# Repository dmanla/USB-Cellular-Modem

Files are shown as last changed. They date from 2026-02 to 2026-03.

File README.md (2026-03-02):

# USB-Cellular-Modem: NB-IoT/Cat-M Terminal

## Overview
**USB-Cellular-Modem** is an open-hardware cellular terminal designed for to enable any device equipped with USB to interface with LTE-CAT-M1 or NB-IOT Cellular Networks. The modem is low-power enough to be used as a back-up cellular interface for any mobile device. 

**NOTE:** Due to Apple restrictions on USB Interface access, this device cannot interface with Apple Devices. There may be a bluetooth variant in the future.

The core of the device is the **SIMCOM 7080G**, providing global NB-IoT and Cat-M1 connectivity with a focus on a minimal RF footprint and user-controlled privacy.

---

## Key Security & Design Features
* **Active-Discharge Kill Switch**: A physical SPDT slide switch ($SW1$) that disconnects the buck converter and actively shorts the $+BATT$ rail to ground through a $10\Omega$ resistor ($R4$). This ensures the $1000\mu F$ bulk capacitance is drained in milliseconds, preventing any residual "heartbeat" transmissions.
* **UART Signal Isolation**: $1k\Omega$ series resistors ($R8$, $R9$, $R10$, $R11$) are placed on all data lines (TX, RX, RTS, DTR). This prevents the **CH343P** from "back-powering" the modem via internal ESD diodes when the master power is cut.
* **Automated Power Trigger**: The **DTR** line is tied to a **DTC143Z** digital transistor ($Q1$). Opening the serial port on the host machine automatically pulses the modem's **PWRKEY**, initiating the boot sequence.
* **Local RF Shielding**: The PCB includes grounded rectangular frames designed for soldering a metal Faraday cage over the antenna matching network ($J1$, $C2$, $R1$, $C3$) to mitigate local signal sniffing.
* **eSIM Integration**: Includes a dedicated footprint for the **ST4SIM-200M** GSMA-certified eSIM for tamper-resistant credential storage.

---

### Included Hardware
| Component | Part Number | Description |
| :--- | :--- | :--- |
| **Cellular Module** | **SIMCOM 7080G** | Global NB-IoT / Cat-M1 with GNSS. |
| **USB-UART Bridge** | **WCH CH343P** | High-speed USB to serial converter. |
| **Power Regulator** | **TPS62A01ADRL** | 1000mA Synchronous Buck Converter (5V to 3.8V). |
| **Embedded SIM** | **ST4SIM-200M** | Industrial-grade MFF2 eSIM. |
| **Nano SIM Slot** | **CUI Hinged NSIM-2** | Nano-SIM Card Slot. |

---

## Technical Specifications
* **Input Power**: USB VBUS (+5V, 500mA).
* **Logic Level**: $1.8V$ Internal ($VDD\_EXT$), isolated from $3.3V$ USB signals.
* **Stackup**: 4-Layer PCB with solid internal ground planes.
* **EDA Software**: **KiCad 9.0.7**.

## Usage
1.  **Enable Device**: Flip $SW1$ to the `ON` position.
2.  **Communication**: Open a serial terminal (e.g., `minicom` or `screen`) at `115200` baud. The DTR toggle will boot the modem.
3.  **Kill Session**: Flip $SW1$ to the `OFF` position. The modem is physically disconnected and the power rail is grounded.

---

## Front 3D Render


## Back 3D Render


## License

Dimensions and Modem Placement Derived from [techstudio-design/sim7080_dev_board](https://github.com/techstudio-design/sim7080_dev_board)

All PCB design files and hardware are released under the [Creative Commons Attribution Share Alike 4.0](https://choosealicense.com/licenses/cc-by-sa-4.0/) license.

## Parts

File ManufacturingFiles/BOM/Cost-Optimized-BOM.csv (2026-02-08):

Reference | Qty | Value/Description | Manufacturer | Part Number | Distributor | Unit Price (10 Qty) | Total (10 Qty)
U2 | 1 | Cellular Module Cat-M/NB-IoT | SimCom | SIM7080G | LCSC (C2943992) | $10.86 | $108.60
U3 | 1 | eSIM IC GSMA | STMicroelectronics | ST4SIM-200M | Mouser / ST | $3.00 | $30.00
U7 | 1 | USB to UART Bridge | WCH | CH343P | LCSC (C2846043) | $1.03 | $10.30
U6 | 1 | Buck Converter 1A | Texas Instruments | TPS62A01ADRLR | DigiKey / Mouser | $0.13 | $1.30
U1,U4 | 2 | ESD Protection 2-Line | Yenji Elec | USBLC6-2SC6 | LCSC (C323793) | $0.07 | $1.40
D2 | 1 | TVS Diode Array 5-Line | STMicroelectronics | ESDA6V1W5 | LCSC (C48677) | $0.10 | $1.00
C1,C18 | 2 | 470uF 6.3V Tantalum Case D | Kyocera AVX | TAJD477K006RNJ | LCSC (C7229) | $0.86 | $17.20
J1 | 1 | U.FL Connector (SMT) | Hirose (HRS) | U.FL-R-SMT-1(80) | LCSC (C88374) | $0.13 | $1.30
J3 | 1 | USB Micro-B Connector | Shou Han | Micro-USB-5P | LCSC (C10418) | $0.04 | $0.40
J4 | 1 | Nano SIM Connector Hinged | Shou Han | NANO SIM 7P H1.37 | LCSC (C7529384) | $0.27 | $2.70
SW1 | 1 | Slide Switch SPDT | XKB Connectivity | SS-12D10-G5 | LCSC (C394953) | $0.03 | $0.30
F1 | 1 | PTC Fuse 1.1A 1206 | SART | SMD1206-110-16V | LCSC (C20537) | $0.04 | $0.40
L1 | 1 | Inductor 1uH 1A 1210 | Sunlord | SWPA3015S1R0MT | LCSC (C1046) | $0.05 | $0.50
Q1,Q2,Q3 | 3 | Digital Transistor NPN | Changjiang | DTC143ZUA | LCSC (C151046) | $0.02 | $0.60
D3 | 1 | LED Blue 0603 | Hubei Kento | 19-217/BHC-ZL1M2RY/3T | LCSC (C2293) | $0.02 | $0.20
D4 | 1 | LED Red 0603 | Hubei Kento | 17-21/R6C-AP1Q2L/3T | LCSC (C2290) | $0.02 | $0.20
C4,C5 | 2 | 100uF 6.3V X5R 1206 | Samsung | CL31A107MQHNNNE | LCSC (C14863) | $0.14 | $2.80
C17 | 1 | 22uF 10V X5R 0805 | Samsung | CL21A226MPQNNNE | LCSC (C15652) | $0.03 | $0.30
C16 | 1 | 10uF 10V X5R 0805 | Samsung | CL21A106KPCLQNC | LCSC (C15783) | $0.01 | $0.10
C6,C10,C13 | 3 | 1uF 16V X7R 0603 | Samsung | CL10B105KO8NNNC | LCSC (C15849) | $0.00 | $0.12
C11 | 1 | 100nF 16V X7R 0603 | Samsung | CL10B104KB8NNNC | LCSC (C1525) | $0.00 | $0.03
C7,C8,C9 | 3 | 100nF 16V X7R 0603 | Samsung | CL10B104KB8NNNC | LCSC (C1525) | $0.00 | $0.09
C12 | 1 | 120pF 50V C0G 0603 | Samsung | CL10C121JB8NNNC | LCSC (C1548) | $0.00 | $0.03
R6 | 1 | 100k 1% 0603 | Uni-Royal | 0603WAF1003T5E | LCSC (C25804) | $0.00 | $0.02
R5 | 1 | 536k 1% 0603 | Uni-Royal | 0603WAF5363T5E | LCSC (C23187) | $0.00 | $0.02
R2 | 1 | 10k 1% 0603 | Uni-Royal | 0603WAF1002T5E | LCSC (C25744) | $0.00 | $0.02
R3,R7,R8,R9,R11 | 5 | 1k 1% 0603 | Uni-Royal | 0603WAF1001T5E | LCSC (C25741) | $0.00 | $0.10
R4 | 1 | 10R 1% 1210 | Uni-Royal | 1210WAF100JT5E | LCSC (C17918) | $0.01 | $0.10
R1 | 1 | 0R Jumper 0603 | Uni-Royal | 0603WAF0000T5E | LCSC (C21189) | $0.00 | $0.02
JP1 | 1 | Solder Jumper Open | N/A | N/A | N/A | $0.00 | $0.00
J2 | 1 | Pin Header 1x04 | Generic | 2.54mm-1x4P | LCSC (C124375) | $0.01 | $0.10
H1-H4 | 4 | Mounting Hole M2.5 | N/A | N/A | N/A | $0.00 | $0.00
C2,C3 | 2 | DNP | N/A | N/A | N/A | $0.00 | $0.00
 |  |  |  |  |  | Total Unit Cost (Qty: 10) | $18.03

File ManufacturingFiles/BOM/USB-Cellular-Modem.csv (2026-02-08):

Reference | Qty | Value/Description | Footprint | Manufacturer | Part Number | Unit Price (10 Qty) | Total (10 Qty)
U2 | 1 | Cellular Module Cat-M/NB-IoT | LCC-80 (17.6x15.7mm) | SimCom | SIM7080G | $19.72 | $197.20
U3 | 1 | eSIM IC GSMA | VFDFPN8 (2x3mm) | STMicroelectronics | ST4SIM-200M | $3.00 | $30.00
U7 | 1 | USB to UART Bridge | QFN-16 (3x3mm) | WCH | CH343P | $1.03 | $10.30
U6 | 1 | Buck Converter 1A | SOT-563 | Texas Instruments | TPS62A01ADRLR | $0.13 | $1.30
U1,U4 | 2 | ESD Protection 2-Line | SOT-23-6 | STMicroelectronics | USBLC6-2SC6 | $0.24 | $4.80
D2 | 1 | TVS Diode Array 5-Line | SOT-353 (SC-70-5) | STMicroelectronics | ESDA6V1W5 | $0.24 | $2.40
C1,C18 | 2 | 470uF 6.3V Tantalum Case D | 2917 (7343 Metric) | Vishay / Sprague | TR3D477M6R3C0200 | $1.45 | $29.00
J1 | 1 | U.FL Connector | U.FL (SMT) | Hirose | U.FL-R-SMT-1(10) | $1.10 | $11.00
J3 | 1 | USB Micro-B Connector | USB Micro-B (SMT) | XKB Connectivity | U254-051T-4BH83-F1S | $0.13 | $1.30
J4 | 1 | Nano SIM Connector Hinged | Nano-SIM (SMT) | CUI Devices | NSIM-2-C | $0.55 | $5.50
SW1 | 1 | Slide Switch SPDT | SPDT Right Angle | C&K | OS102011MA1Q | $0.54 | $5.40
F1 | 1 | PTC Fuse 1.1A Hold | 1206 (3216 Metric) | Bel Fuse | 0ZCJ0110FF2E | $0.22 | $2.20
L1 | 1 | Inductor 1uH 1A | 1210 (3225 Metric) | Murata | LQH32CN1R0M33L | $0.08 | $0.80
Q1,Q2,Q3 | 3 | Digital Transistor NPN | SOT-323 (SC-70) | Rohm Semiconductor | DTC143ZUA | $0.23 | $6.90
D3 | 1 | LED Blue (NETLIGHT) | 0603 (1608 Metric) | Lite-On | LTST-C190TBKT | $0.10 | $1.00
D4 | 1 | LED Red (STATUS) | 0603 (1608 Metric) | Lite-On | LTST-C190KRKT | $0.10 | $1.00
C4,C5 | 2 | 100uF 6.3V X5R | 1206 (3216 Metric) | Samsung | CL31A107MQHNNNE | $0.20 | $4.00
C17 | 1 | 22uF 10V X5R | 0805 (2012 Metric) | Samsung | CL21A226MPQNNNE | $0.10 | $1.00
C16 | 1 | 10uF 10V X5R | 0805 (2012 Metric) | Samsung | CL21A106KPCLQNC | $0.05 | $0.50
C6,C10,C13 | 3 | 1uF 16V X7R | 0603 (1608 Metric) | Yageo | CC0603KRX7R7BB105 | $0.02 | $0.60
C11 | 1 | 100nF 16V X7R | 0603 (1608 Metric) | Yageo | CC0603KRX7R7BB104 | $0.01 | $0.10
C7,C8, | 2 | DNP | 0603 (1608 Metric) | N/A | N/A | $0.00 | $0.00
 |  |  |  |  |  | Unit Cost (Qty: 10) | $31.63

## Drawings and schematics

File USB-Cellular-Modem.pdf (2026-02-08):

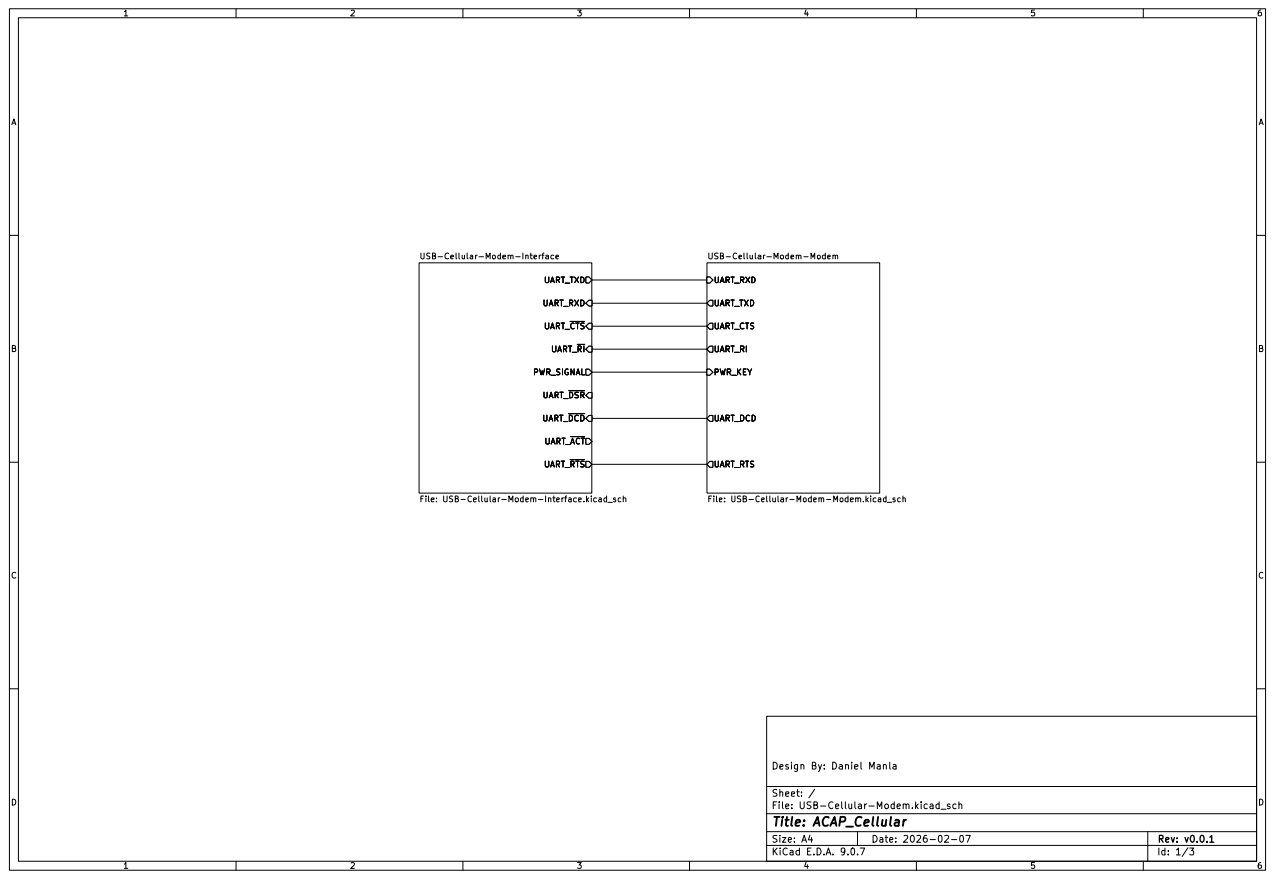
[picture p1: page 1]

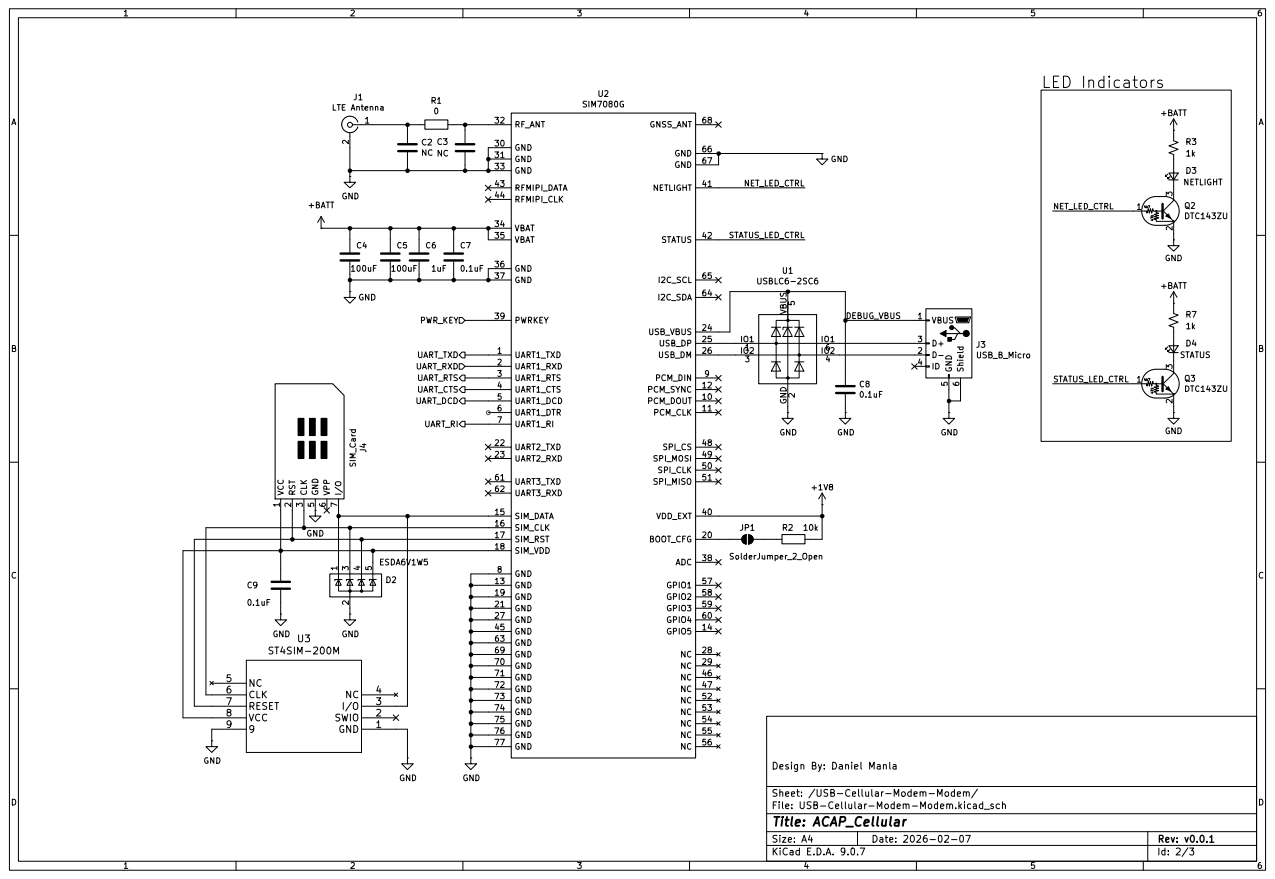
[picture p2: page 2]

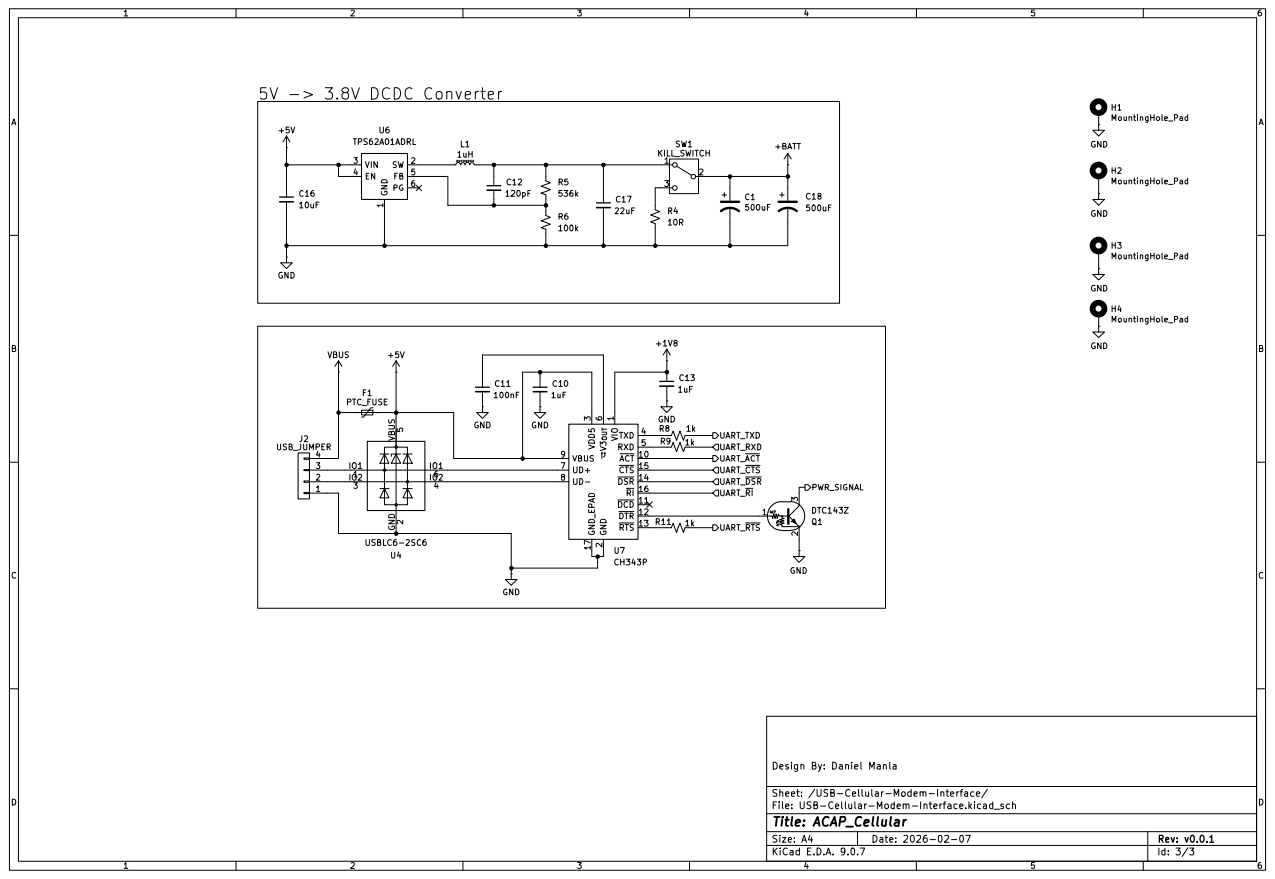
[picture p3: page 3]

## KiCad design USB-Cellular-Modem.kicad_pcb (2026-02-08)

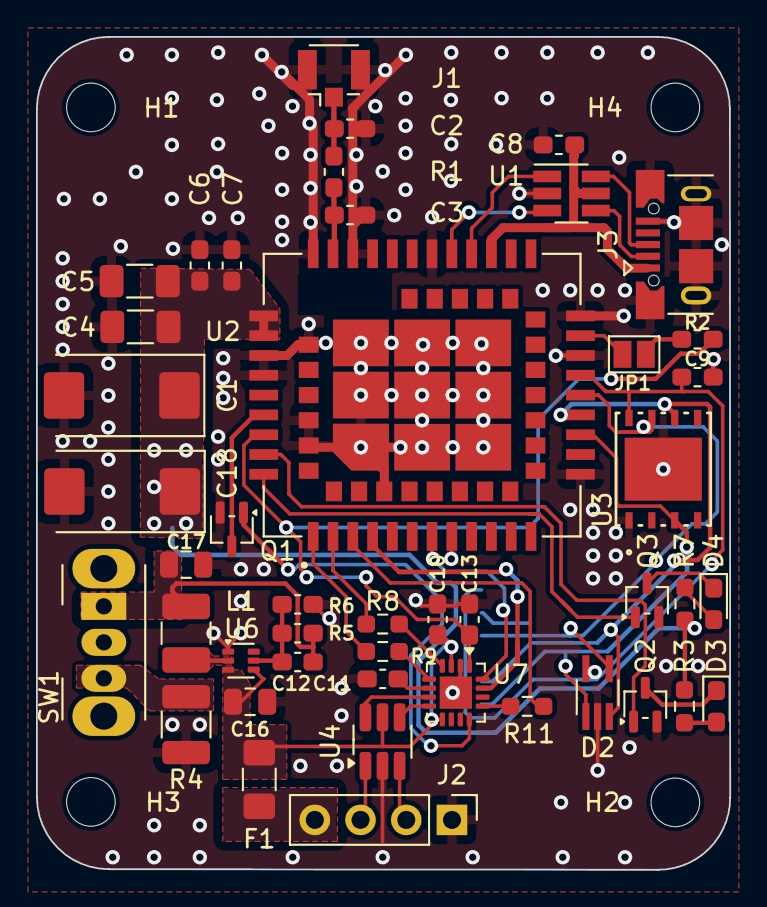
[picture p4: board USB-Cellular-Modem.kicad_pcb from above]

Board: 4 copper layers, 38.5 x 46.3 mm, 50 parts (1 on the bottom side), 43 nets.

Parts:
C1, C18: 500uF; CP_EIA-7343-30_AVX-N_HandSolder
C2, C3: NC; C_0603_1608Metric_Pad1.05x0.95mm_HandSolder
C4, C5: 100uF; C_1206_3216Metric_Pad1.33x1.80mm_HandSolder
C6: 1uF; C_0603_1608Metric_Pad1.05x0.95mm_HandSolder
C7, C8, C9: 0.1uF; C_0603_1608Metric_Pad1.05x0.95mm_HandSolder
C10, C13: 1uF; C_0603_1608Metric_Pad1.08x0.95mm_HandSolder
C11: 100nF; C_0603_1608Metric_Pad1.08x0.95mm_HandSolder
C12: 120pF; C_0603_1608Metric_Pad1.08x0.95mm_HandSolder
C16: 10uF; C_0805_2012Metric
C17: 22uF; C_0805_2012Metric
D2: ESDA6V1W5; SOT-353_SC-70-5_Handsoldering
D3: NETLIGHT; LED_0603_1608Metric_Pad1.05x0.95mm_HandSolder
D4: STATUS; LED_0603_1608Metric_Pad1.05x0.95mm_HandSolder
F1: PTC_FUSE; Fuse_1206_3216Metric_Pad1.42x1.75mm_HandSolder
H1, H2, H3, H4: MountingHole_Pad; MountingHole_2.7mm_M2.5
J1: LTE Antenna; U.FL_Hirose_U.FL-R-SMT-1_Vertical
J2: USB_JUMPER; PinHeader_1x04_P2.54mm_Vertical
J3: USB_B_Micro; USB_Micro-B_XKB_U254-051T-4BH83-F1S
J4: SIM_Card; nanoSIM_Hinged_CUI_NSIM-2-C
JP1: SolderJumper_2_Open; SolderJumper-2_P1.3mm_Open_Pad1.0x1.5mm
L1: 1uH; L_1210_3225Metric_Pad1.42x2.65mm_HandSolder
Q1: DTC143Z; SOT-323_SC-70
Q2, Q3: DTC143ZU; SOT-323_SC-70
R1: 0; R_0603_1608Metric_Pad1.05x0.95mm_HandSolder
R2: 10k; R_0603_1608Metric_Pad1.05x0.95mm_HandSolder
R3, R7, R8, R9, R11: 1k; R_0603_1608Metric_Pad0.98x0.95mm_HandSolder
R4: 10R; R_1210_3225Metric_Pad1.30x2.65mm_HandSolder
R5: 536k; C_0603_1608Metric_Pad1.08x0.95mm_HandSolder
R6: 100k; C_0603_1608Metric_Pad1.08x0.95mm_HandSolder
SW1: KILL_SWITCH; SW_Slide_SPDT_Angled_CK_OS102011MA1Q
U1, U4: USBLC6-2SC6; SOT-23-6_Handsoldering
U2: SIM7080G
U3: ST4SIM-200M
U6: TPS62A01ADRL; SOT-563
U7: CH343P; WCH_QFN-16-1EP_3x3mm_P0.5mm_EP1.8x1.8mm

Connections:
+1V8: C13.1, R2.1, U2.40 (VDD_EXT), U7.1 (VIO)
+5V: C10.1, C16.1, F1.2, U4.5 (VBUS), U6.3 (VIN), U6.4 (EN), U7.3 (VDD5), U7.9 (VBUS)
+BATT: C1.1, C4.1, C5.1, C6.1, C7.1, C18.1, R3.1, R7.1, SW1.2 (B), U2.34 (VBAT), U2.35 (VBAT)
/SIM7080_Interface/PWR_SIGNAL: Q1.3 (C), U2.39 (PWRKEY)
/SIM7080_Interface/UART_RXD: R9.2, U2.1 (UART1_TXD)
/SIM7080_Interface/UART_TXD: R8.2, U2.2 (UART1_RXD)
/SIM7080_Interface/UART_~CTS: U2.4 (UART1_CTS), U7.15 (~CTS)
/SIM7080_Interface/UART_~RI: U2.7 (UART1_RI), U7.16 (~RI)
/SIM7080_Interface/UART_~RTS: R11.2, U2.3 (UART1_RTS)
/SIM7080_module/DEBUG_VBUS: C8.1, J3.1 (VBUS), U1.5 (VBUS), U2.24 (USB_VBUS)
/SIM7080_module/NET_LED_CTRL: Q2.1 (B), U2.41 (NETLIGHT)
/SIM7080_module/STATUS_LED_CTRL: Q3.1 (B), U2.42 (STATUS)
GND: C1.2, C2.2, C3.2, C4.2, C5.2, C6.2, C7.2, C8.2, C9.2, C10.2, C11.2, C13.2, C16.2, C17.2, C18.2, D2.2 (A), J1.2 (Ext), J2.1, J3.5 (GND), J3.6 (Shield), J4.5 (GND), Q1.2 (E), Q2.2 (E), Q3.2 (E), R4.2, R6.2, U1.2 (GND), U2.8 (GND), U2.13 (GND), U2.19 (GND), U2.21 (GND), U2.27 (GND), U2.30 (GND), U2.31 (GND), U2.33 (GND), U2.36 (GND), U2.37 (GND), U2.45 (GND), U2.63 (GND), U2.66 (GND), U2.67 (GND), U2.69 (GND), U2.70 (GND), U2.71 (GND), U2.72 (GND), U2.73 (GND), U2.74 (GND), U2.75 (GND), U2.76 (GND), U2.77 (GND), U3.1 (GND), U3.9, U4.2 (GND), U6.1 (GND), U7.2 (GND), U7.17 (GND_EPAD)
unnamed: D3.2 (A), R3.2
unnamed: D3.1 (K), Q2.3 (C)
unnamed: D4.2 (A), R7.2
unnamed: D4.1 (K), Q3.3 (C)
unnamed: C2.1, J1.1 (In), R1.2
unnamed: J2.2, U4.3 (IO2)
unnamed: J2.3, U4.1 (IO1)
unnamed: J3.3 (D+), U1.6 (IO1)
unnamed: J3.2 (D-), U1.4 (IO2)
unnamed: D2.3 (K), J4.3 (CLK), U2.16 (SIM_CLK), U3.6 (CLK)
unnamed: D2.1 (K), J4.7 (I/O), U2.15 (SIM_DATA), U3.3 (I/O)
unnamed: D2.4 (K), J4.2 (RST), U2.17 (SIM_RST), U3.7 (RESET)
unnamed: C9.1, D2.5 (K), J4.1 (VCC), U2.18 (SIM_VDD), U3.8 (VCC)
unnamed: JP1.1 (A), U2.20 (BOOT_CFG)
unnamed: JP1.2 (B), R2.2
unnamed: Q1.1 (B), U7.12 (~DTR)
unnamed: C12.1, C17.1, L1.2, R5.1, SW1.1 (A)
unnamed: R4.1, SW1.3 (C)
unnamed: C3.1, R1.1, U2.32 (RF_ANT)
unnamed: U1.3 (IO2), U2.26 (USB_DM)
unnamed: U1.1 (IO1), U2.25 (USB_DP)
unnamed: C12.2, R5.2, R6.1, U6.5 (FB)
unnamed: L1.1, U6.2 (SW)
unnamed: R9.1, U7.5 (RXD)
unnamed: R8.1, U7.4 (TXD)
unnamed: U4.6 (IO1), U7.7 (UD+)
unnamed: U4.4 (IO2), U7.8 (UD-)
unnamed: C11.1, U7.6 (V3_{OUT})
unnamed: R11.1, U7.13 (~RTS)
VBUS: F1.1, J2.4

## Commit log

2026-02-08 add BOM in different formats
    [USB-Cellular-Modem - USB-Cellular-Modem.csv, USB-Cellular-Modem.ods]
2026-02-08 AI Generated Cost Optimized BOM's
    [Cost-Optimized-BOM.ods]

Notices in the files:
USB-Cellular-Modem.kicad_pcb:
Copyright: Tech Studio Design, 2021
